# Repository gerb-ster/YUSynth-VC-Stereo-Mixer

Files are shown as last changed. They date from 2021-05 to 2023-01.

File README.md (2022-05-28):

# YUSynth-VC-Stereo-Mixer

This is my eurorack adaptation of the Mixout-VC Panner from YUSynth. I've ommited
the headphone out the VU meters. This is done because to compact the boards a bit
and to save space on the panels.

I've broken it up into 3 boards, one VoiceBoard for every channel, a mainboard 
containing the mixer and the Bass & Trebble and finally small daughter board for the
left/right output jacks.

The breaks up of the boards is done in such a way that you can decide for yourself
how many channels/voice you want to add.

The original design:
http://yusynth.net/Modular/EN/MIXOUT/index.html

## Status: (Almost) Finished

- done: first schematic & board design
- done: breadboard and test
- done: design frontpanel
- done: order PCB and build prototype
- todo: build frontpanel

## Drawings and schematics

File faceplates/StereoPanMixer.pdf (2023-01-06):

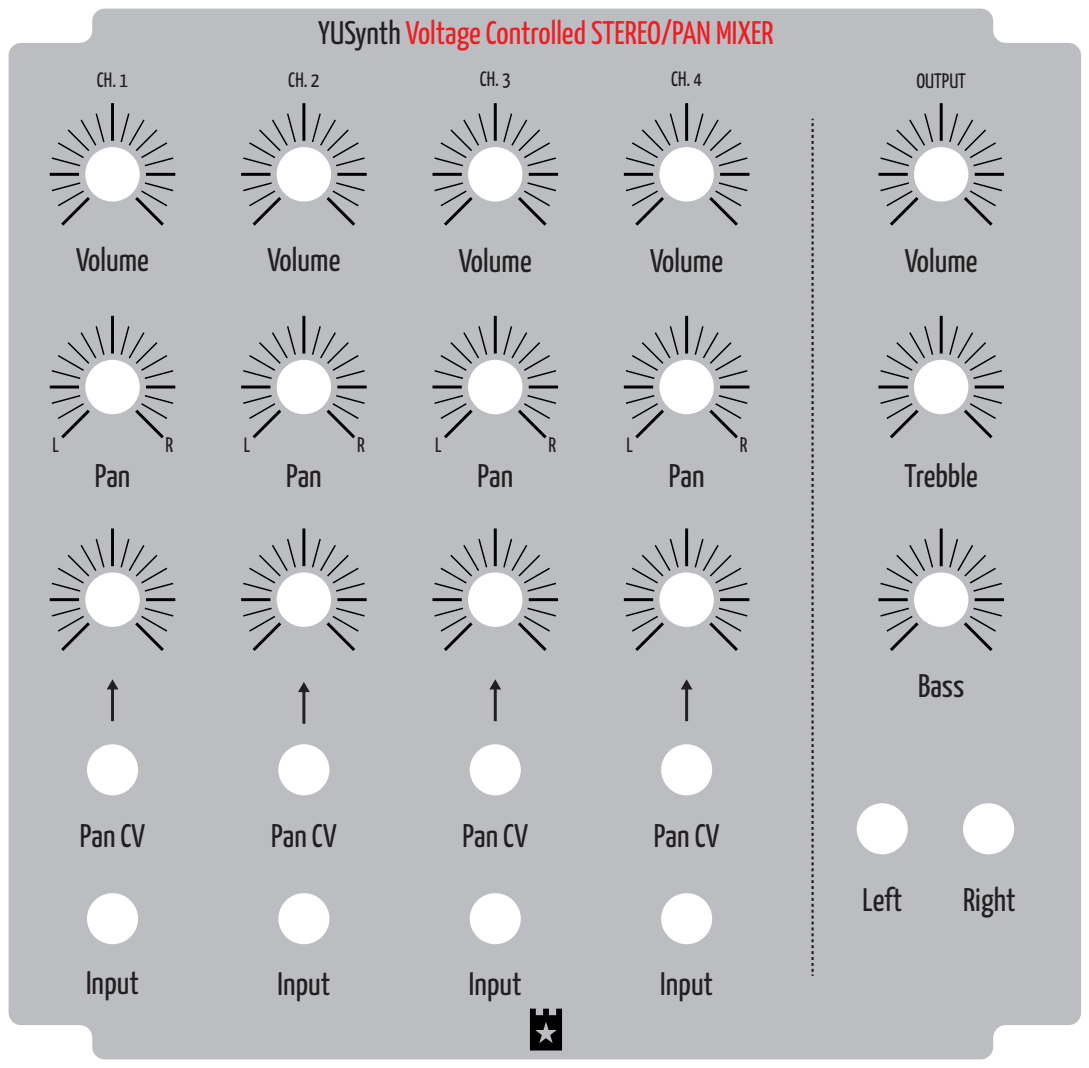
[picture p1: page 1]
Volume; Pan; Trebble; Bass; Pan CV; Input; Left; Right; OUTPUT

YUSynth Voltage Controlled STEREO/PAN MIXER

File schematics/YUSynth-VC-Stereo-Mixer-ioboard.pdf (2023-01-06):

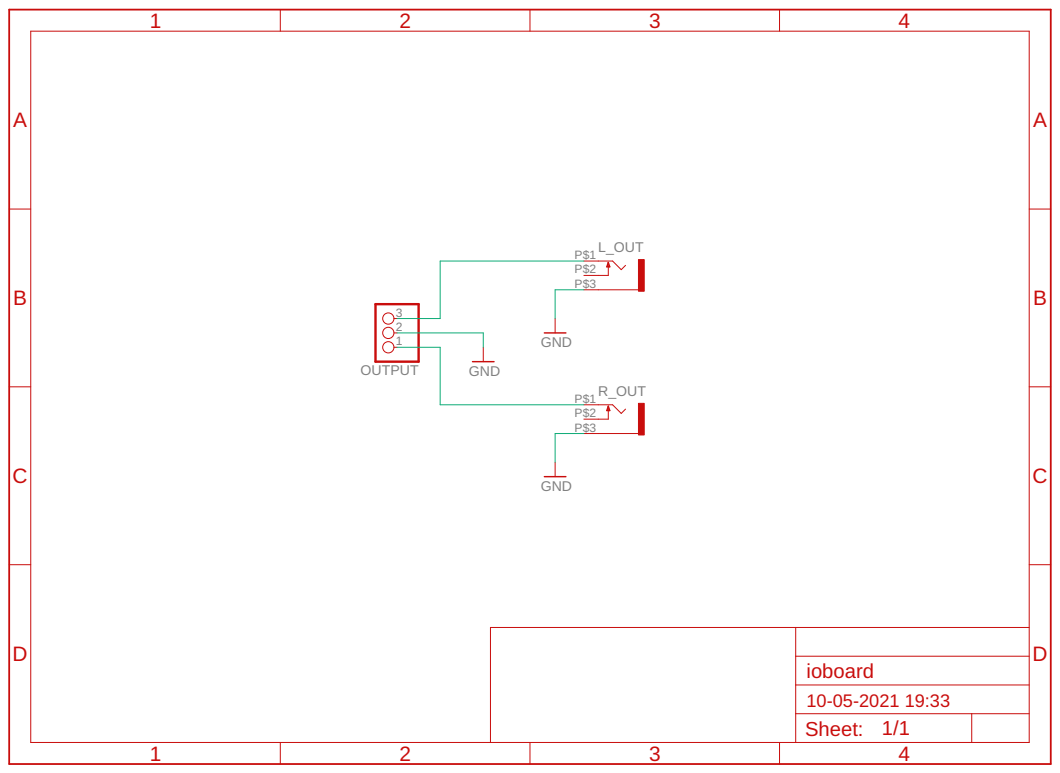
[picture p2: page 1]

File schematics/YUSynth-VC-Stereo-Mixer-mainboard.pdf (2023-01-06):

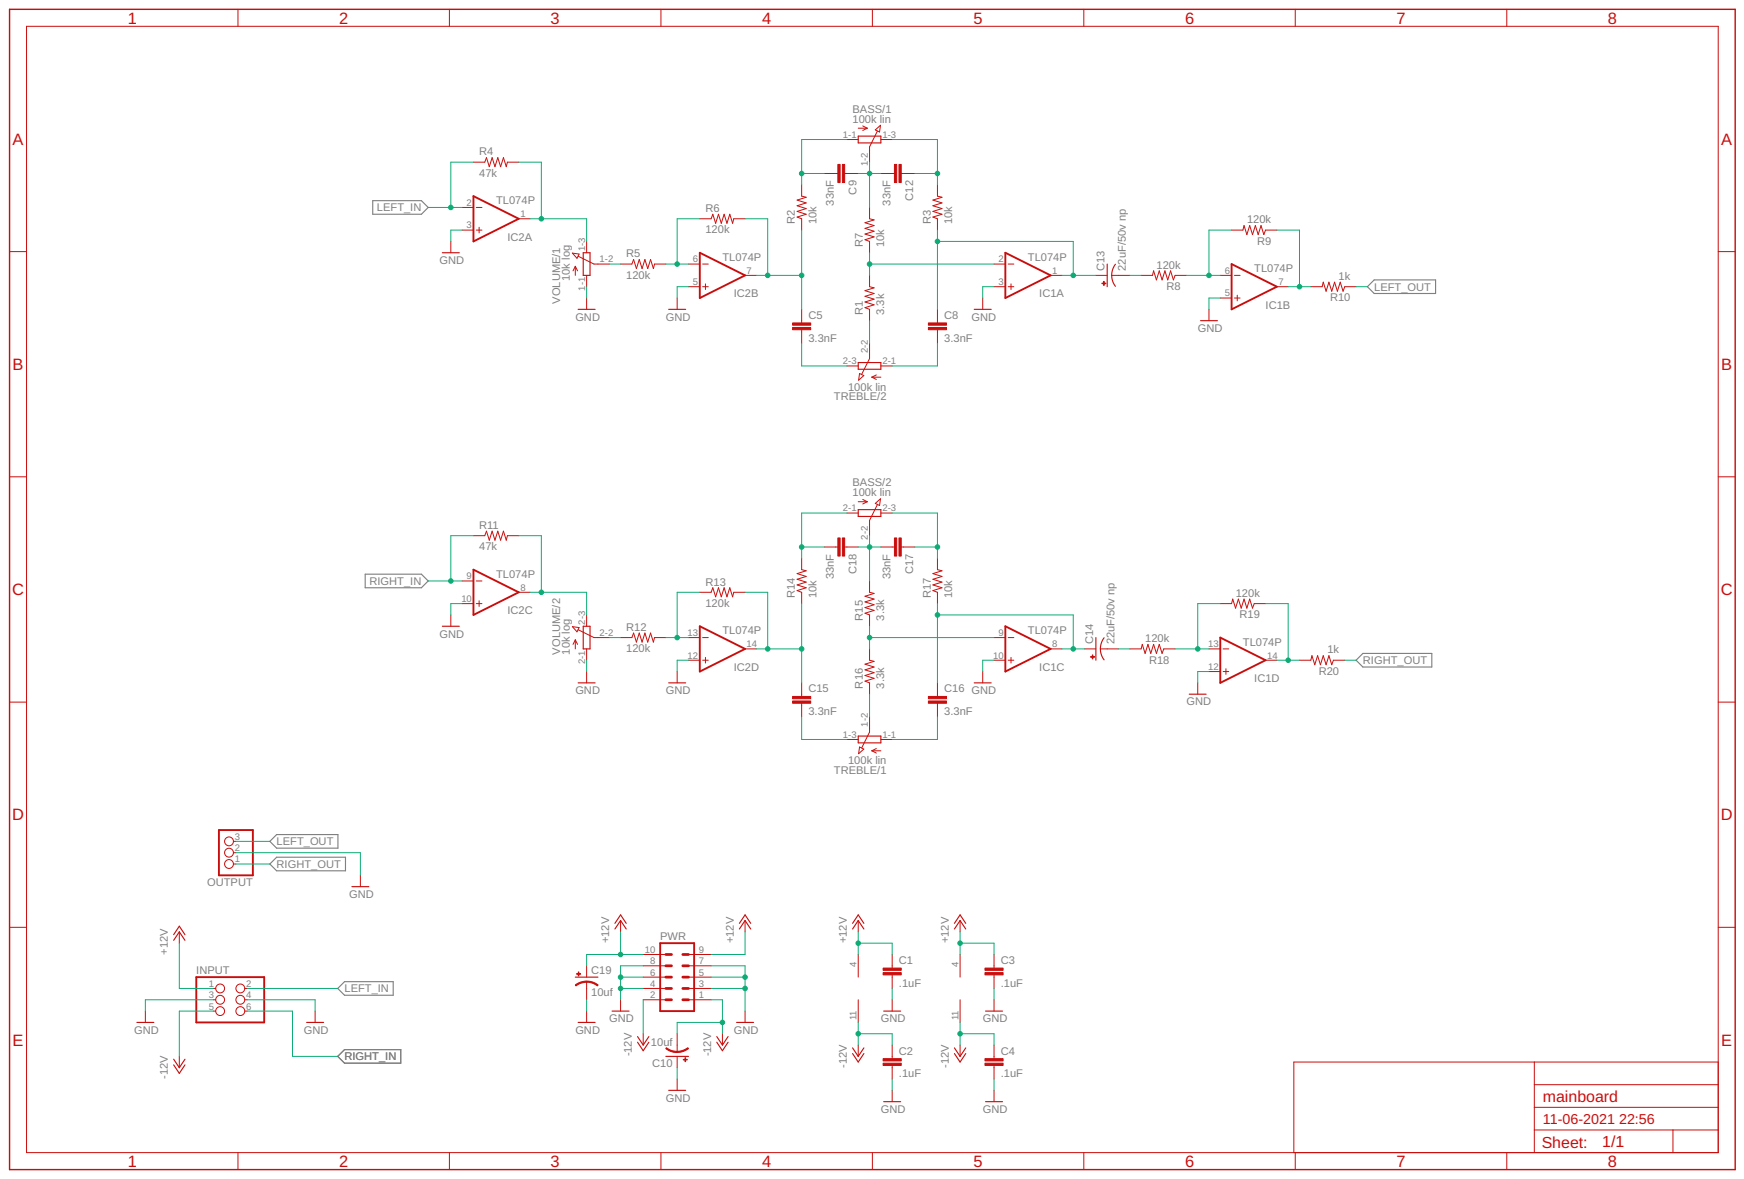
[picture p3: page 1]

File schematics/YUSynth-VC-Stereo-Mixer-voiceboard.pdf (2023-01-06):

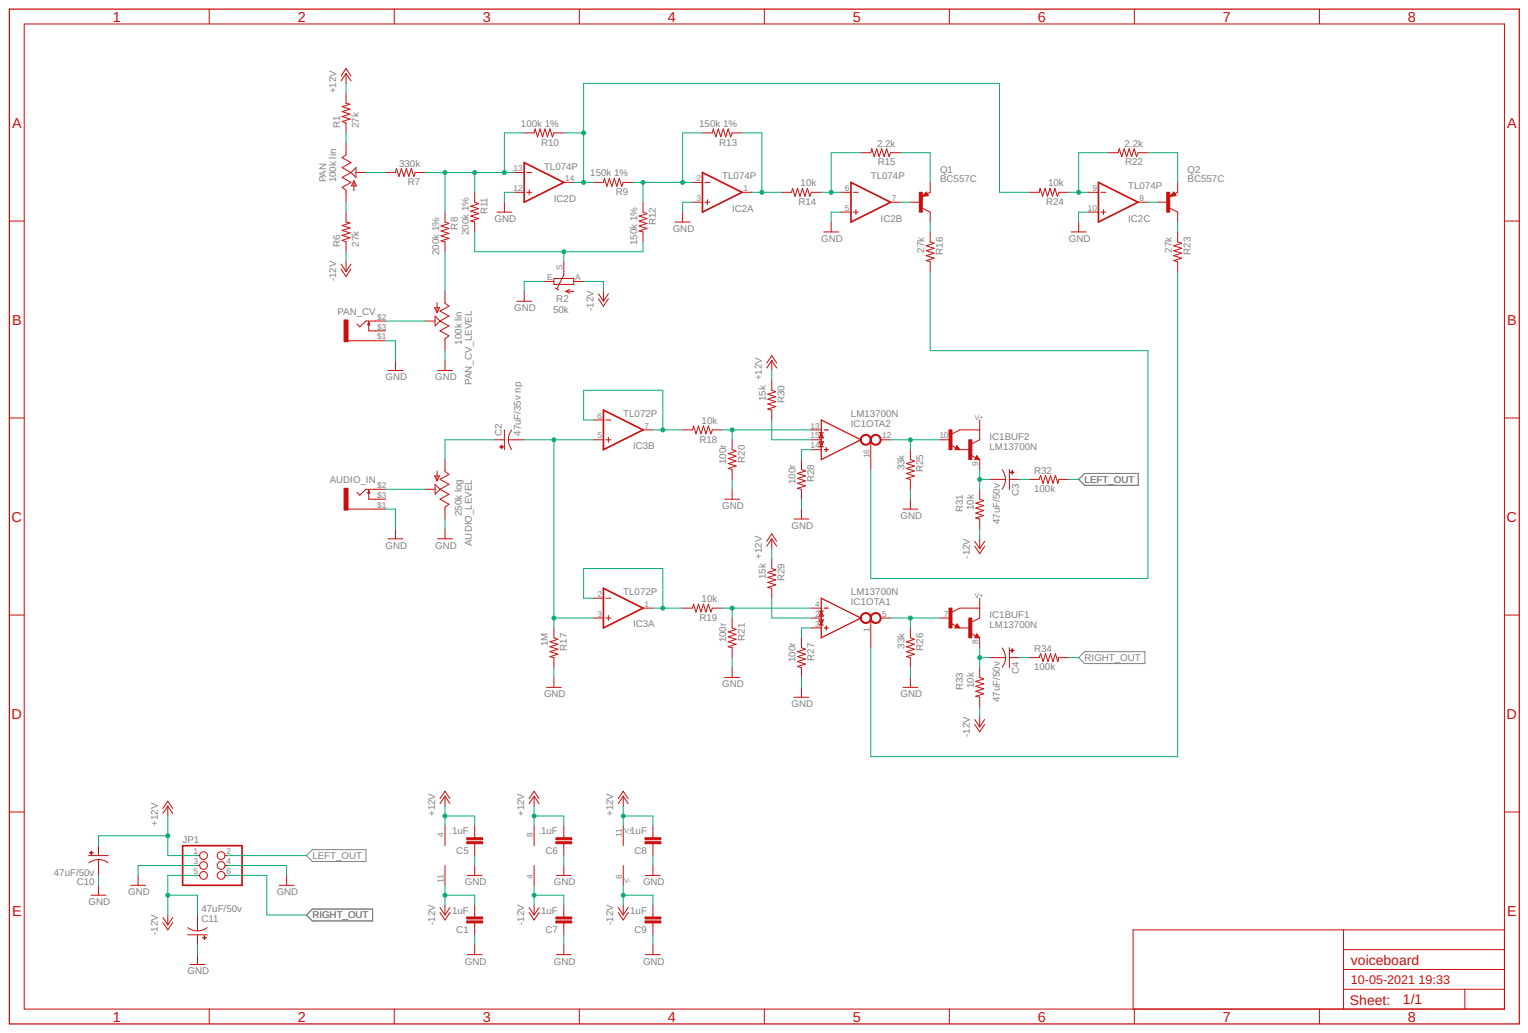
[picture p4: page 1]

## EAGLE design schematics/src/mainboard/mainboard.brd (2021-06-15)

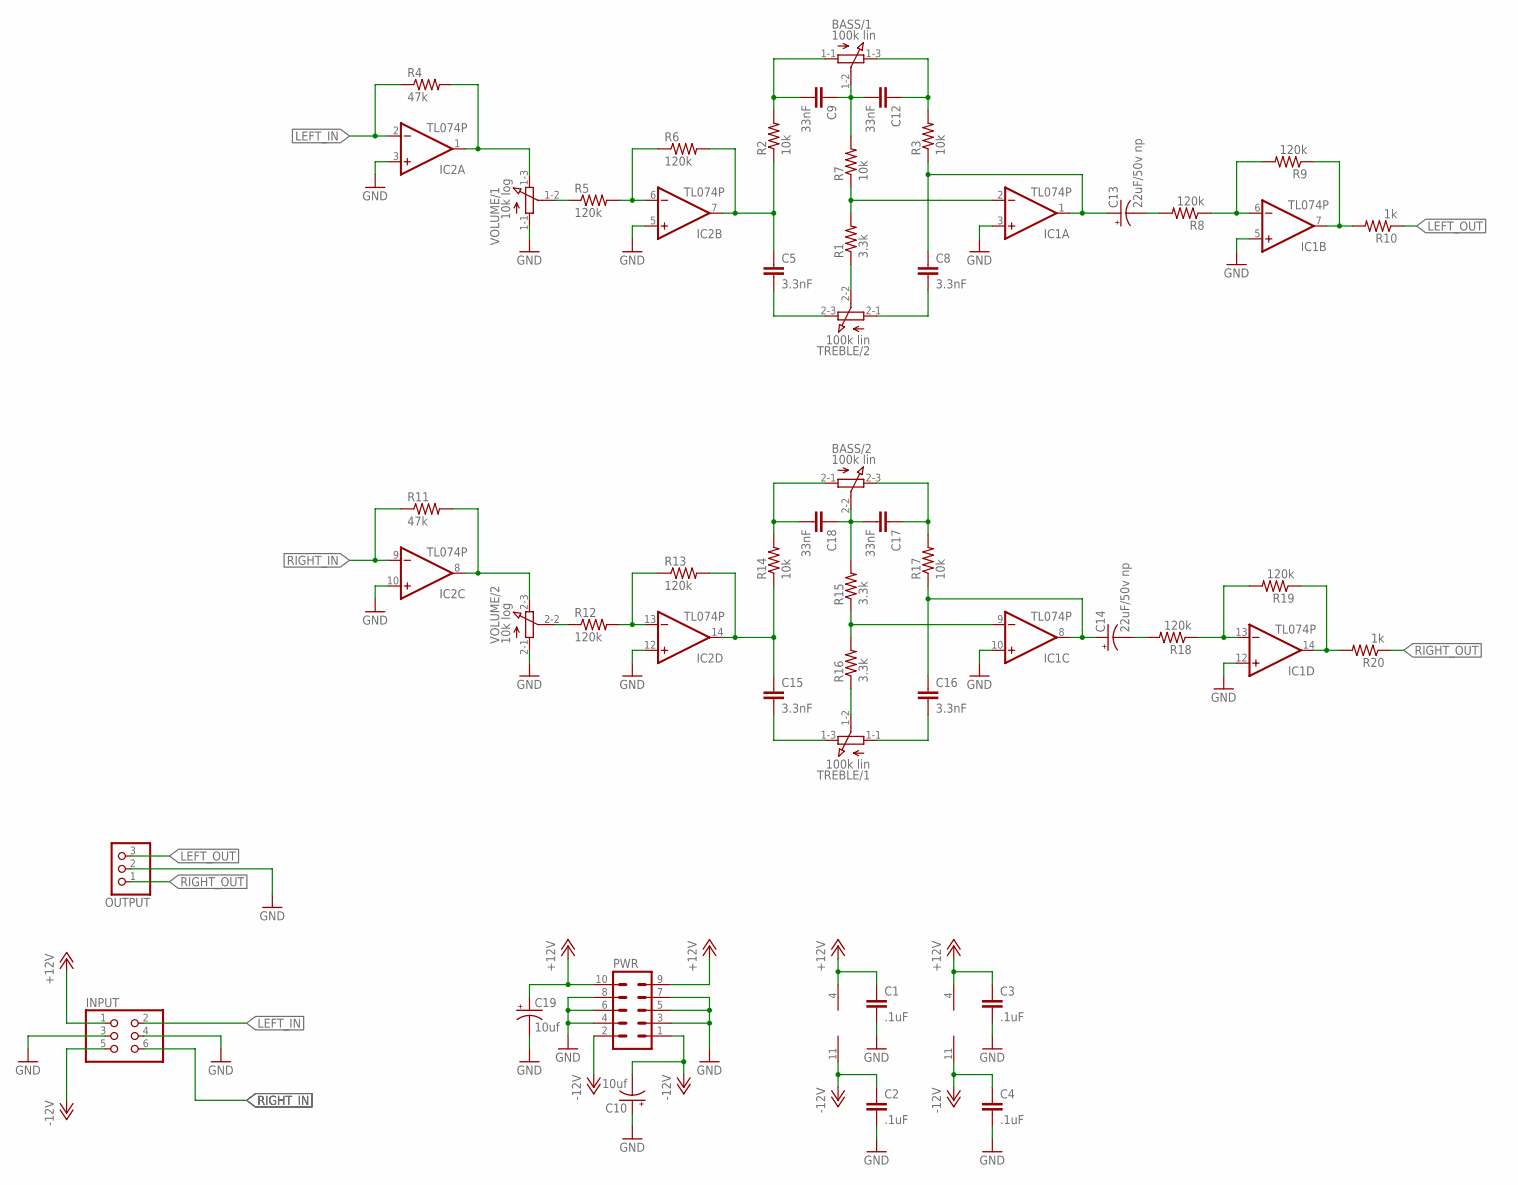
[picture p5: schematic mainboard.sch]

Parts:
BASS: 100k lin; 3RP/1610G
C1, C2, C3, C4: .1uF; C050-024X044
C5, C8, C15, C16: 3.3nF; C050-025X075
C9, C12, C17, C18: 33nF; C050-025X075
C10, C19: 10uf; E2,5-5
C13, C14: 22uF/50v np; E5-10,5
IC1, IC2: TL074P; DIL14
INPUT: PINHD-2X3/90; 2X03/90
OUTPUT: PINHD-1X3; 1X03
PWR: ML10
R1, R15, R16: 3.3k; 0207/7
R2, R3, R7, R14, R17: 10k; 0207/7
R4, R11: 47k; 0207/7
R5, R6, R8, R9, R12, R13, R18, R19: 120k; 0207/7
R10, R20: 1k; 0207/7
TREBLE: 100k lin; 3RP/1610G
VOLUME: 10k log; 3RP/1610G

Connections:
+12V: C1.1, C3.1, C19.+, IC1.4 (V+), IC2.4 (V+), INPUT.1, PWR.9, PWR.10
-12V: C2.1, C4.1, C10.-, IC1.11 (V-), IC2.11 (V-), INPUT.5, PWR.1, PWR.2
GND: C1.2, C2.2, C3.2, C4.2, C10.+, C19.-, IC1.3 (+IN), IC1.5 (+IN), IC1.10 (+IN), IC1.12 (+IN), IC2.3 (+IN), IC2.5 (+IN), IC2.10 (+IN), IC2.12 (+IN), INPUT.3, INPUT.4, OUTPUT.2, PWR.3, PWR.4, PWR.5, PWR.6, PWR.7, PWR.8, VOLUME.1-1 (A), VOLUME.2-1 (A)
LEFT_IN: IC2.2 (-IN), INPUT.2, R4.1
LEFT_OUT: OUTPUT.3, R10.1
unnamed: R5.1, VOLUME.1-2 (S)
unnamed: IC2.1 (OUT), R4.2, VOLUME.1-3 (E)
unnamed: IC2.6 (-IN), R5.2, R6.1
unnamed: C5.1, IC2.7 (OUT), R2.1, R6.2
unnamed: R1.1, TREBLE.2-2 (S)
unnamed: C5.2, TREBLE.2-3 (E)
unnamed: C8.2, TREBLE.2-1 (A)
unnamed: BASS.1-1 (A), C9.2, R2.2
unnamed: BASS.1-3 (E), C12.1, R3.2
unnamed: BASS.1-2 (S), C9.1, C12.2, R7.2
unnamed: IC1.2 (-IN), R1.2, R7.1
unnamed: C8.1, C13.+, IC1.1 (OUT), R3.1
unnamed: IC1.6 (-IN), R8.1, R9.2
unnamed: IC1.7 (OUT), R9.1, R10.2
unnamed: C13.-, R8.2
unnamed: C15.2, TREBLE.1-3 (E)
unnamed: IC2.8 (OUT), R11.2, VOLUME.2-3 (E)
unnamed: R12.1, VOLUME.2-2 (S)
unnamed: IC2.13 (-IN), R12.2, R13.1
unnamed: C16.2, TREBLE.1-1 (A)
unnamed: R16.1, TREBLE.1-2 (S)
unnamed: C15.1, IC2.14 (OUT), R13.2, R14.1
unnamed: IC1.9 (-IN), R15.1, R16.2
unnamed: BASS.2-2 (S), C17.2, C18.1, R15.2
unnamed: BASS.2-1 (A), C18.2, R14.2
unnamed: BASS.2-3 (E), C17.1, R17.2
unnamed: C14.-, R18.2
unnamed: C14.+, C16.1, IC1.8 (OUT), R17.1
unnamed: IC1.13 (-IN), R18.1, R19.2
unnamed: IC1.14 (OUT), R19.1, R20.2
RIGHT_IN: IC2.9 (-IN), INPUT.6, R11.1
RIGHT_OUT: OUTPUT.1, R20.1

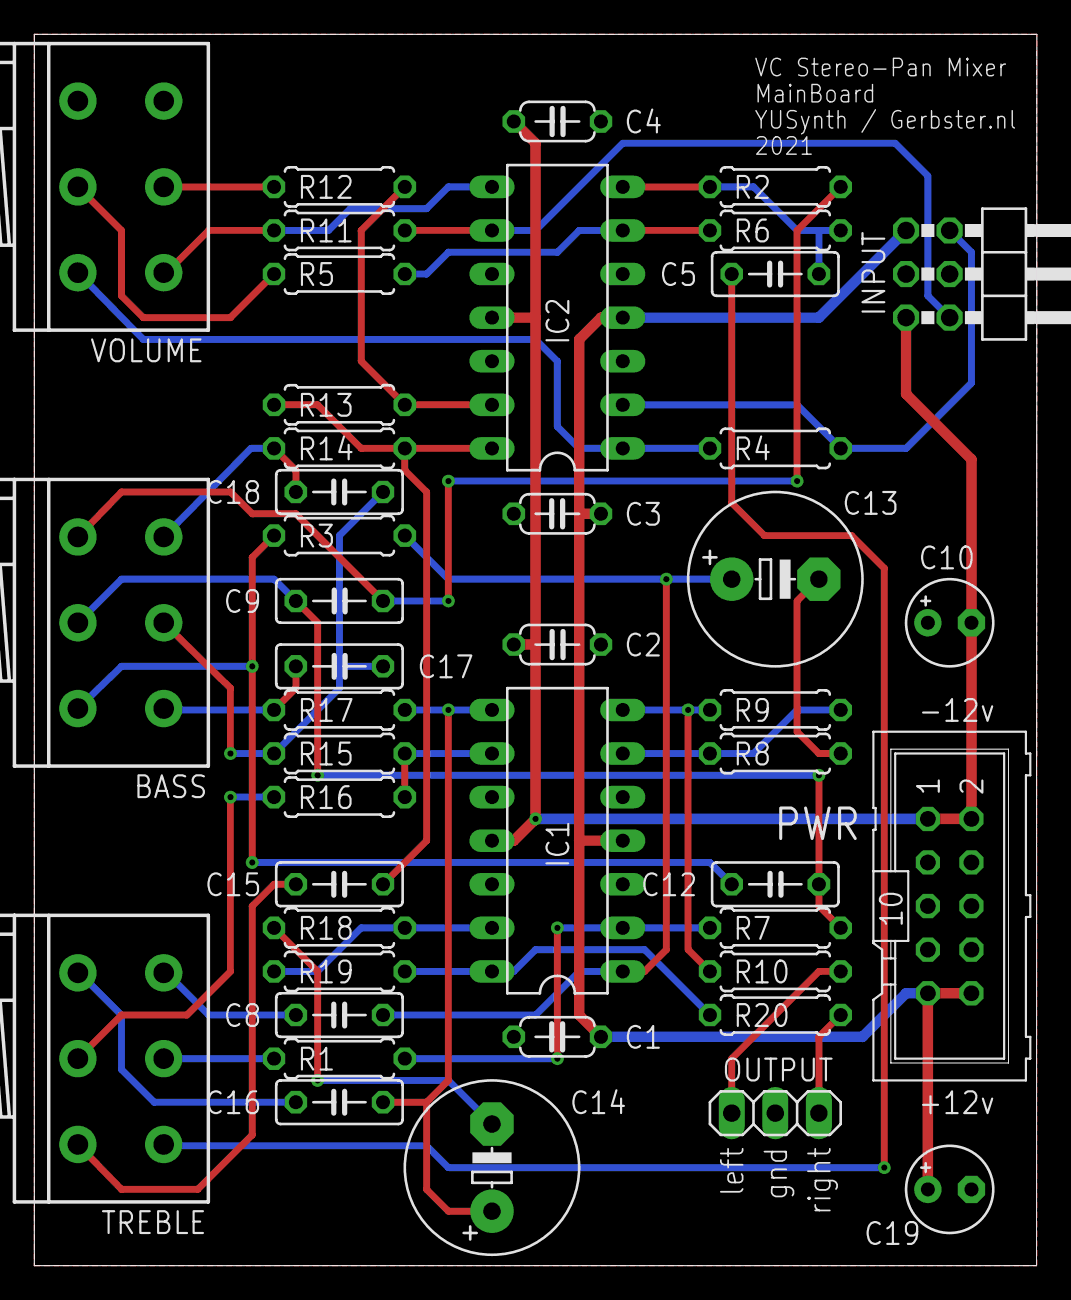
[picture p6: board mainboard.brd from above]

Board: 2 copper layers, 58.4 x 71.8 mm, 44 parts (0 on the bottom side), 37 nets.

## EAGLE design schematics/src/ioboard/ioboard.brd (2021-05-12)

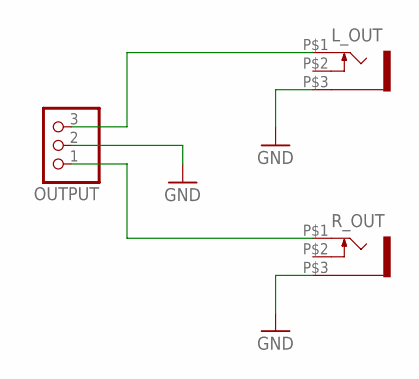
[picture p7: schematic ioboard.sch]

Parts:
L_OUT: WQP-PJ301M-12_JACK
OUTPUT: PINHD-1X3; 1X03
R_OUT: WQP-PJ301M-12_JACK

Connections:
GND: L_OUT.P$3 (1), OUTPUT.2, R_OUT.P$3 (1)
LEFT_OUT: L_OUT.P$1 (2), OUTPUT.3
RIGHT_OUT: OUTPUT.1, R_OUT.P$1 (2)

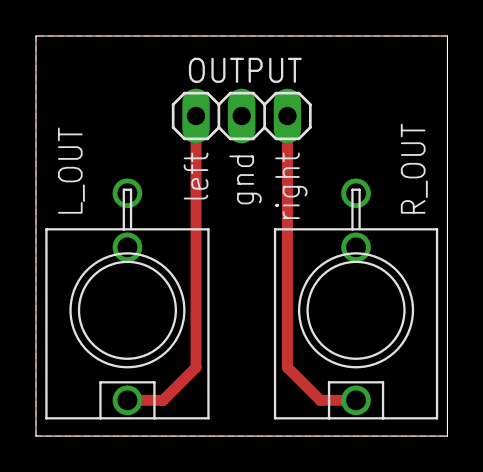
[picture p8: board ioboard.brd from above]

Board: 2 copper layers, 22.9 x 22.2 mm, 3 parts (0 on the bottom side), 3 nets.

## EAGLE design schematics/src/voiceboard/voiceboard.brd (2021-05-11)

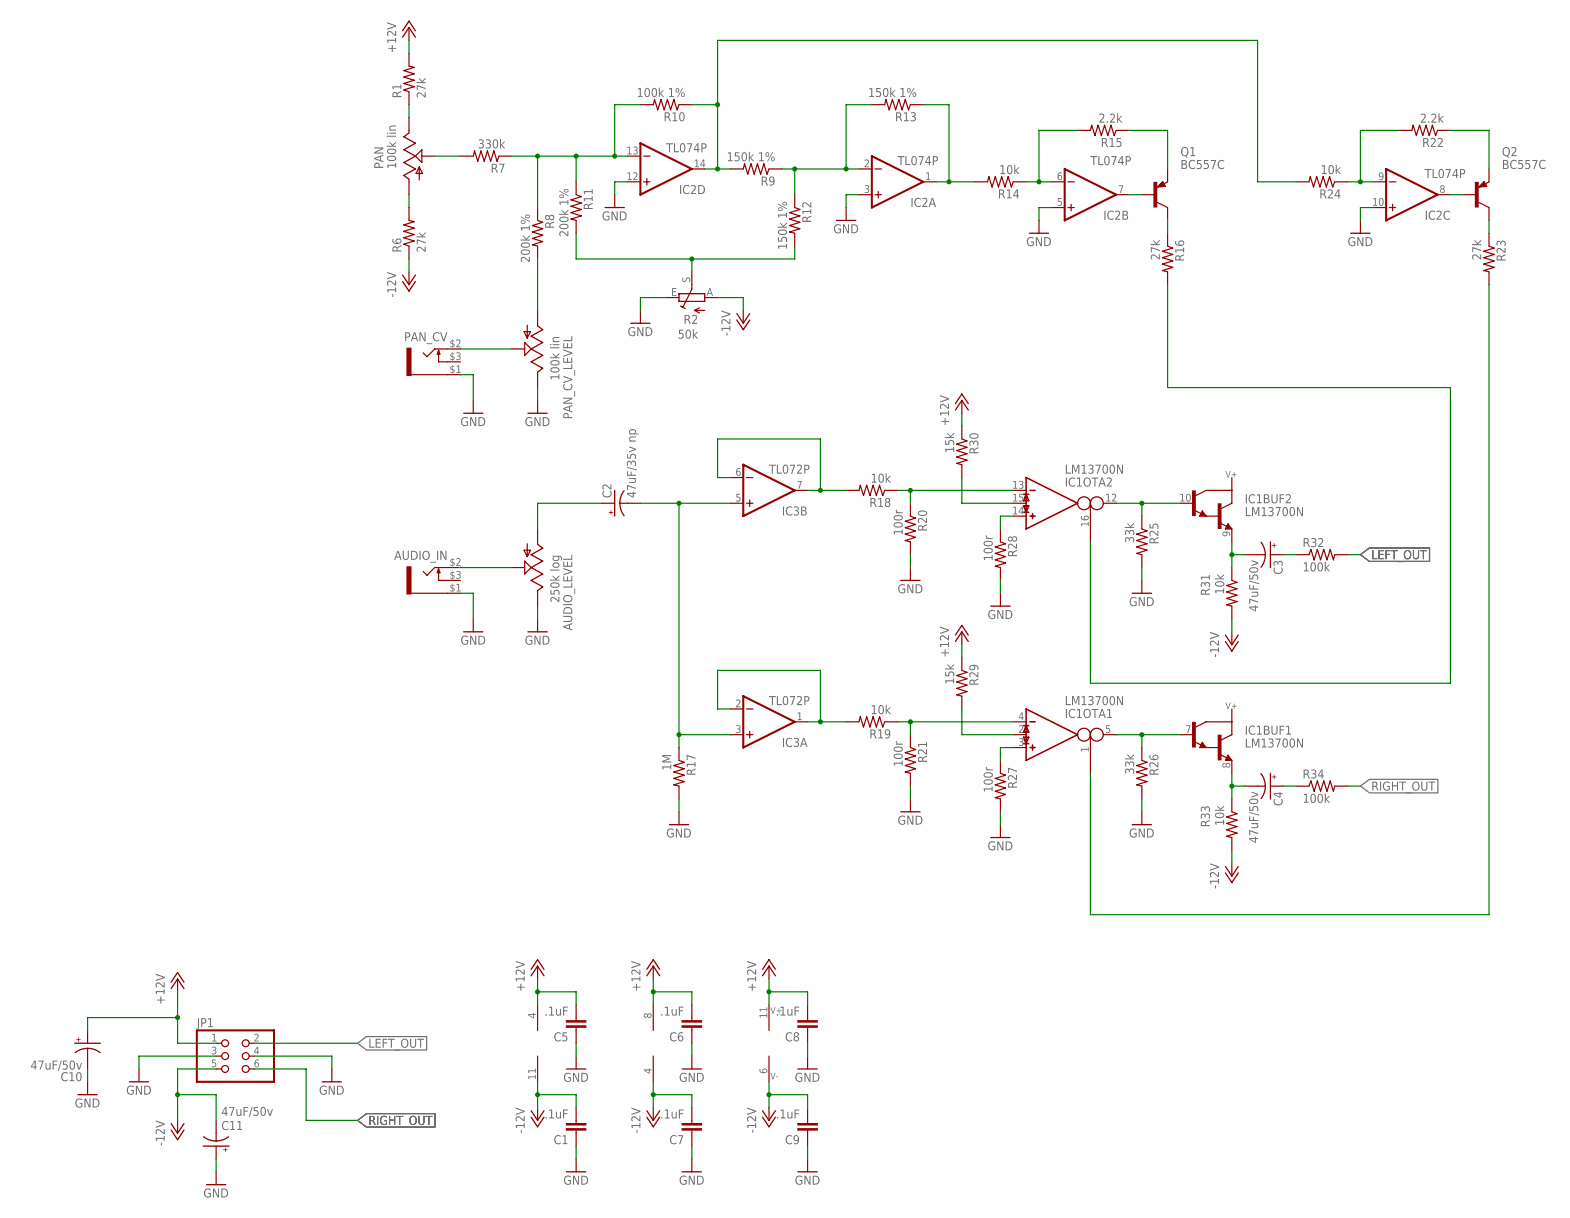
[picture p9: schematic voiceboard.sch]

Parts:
AUDIO_IN: PJ-323PJ-323; PJ-323
AUDIO_LEVEL: 250k log; EVUF
C1, C5, C6, C7, C8, C9: .1uF; C050-024X044
C2: 47uF/35v np; E5-10,5
C3, C4, C10, C11: 47uF/50v; E2,5-6
IC1: LM13700N; DIL16
IC2: TL074P; DIL14
IC3: TL072P; DIL08
JP1: PINHD-2X3/90; 2X03/90
PAN: 100k lin; EVUF
PAN_CV: PJ-323PJ-323; PJ-323
PAN_CV_LEVEL: 100k lin; EVUF
Q1, Q2: BC557C; TO92-EBC
R1, R6, R16, R23: 27k; 0207/7
R2: 50k; S64YW
R7: 330k; 0207/7
R8, R11: 200k 1%; 0207/7
R9, R12, R13: 150k 1%; 0207/7
R10: 100k 1%; 0207/7
R14, R18, R19, R24, R31, R33: 10k; 0207/7
R15, R22: 2.2k; 0207/7
R17: 1M; 0207/7
R20, R21, R27, R28: 100r; 0207/7
R25, R26: 33k; 0207/7
R29, R30: 15k; 0207/7
R32, R34: 100k; 0207/7

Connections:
+12V: C5.2, C6.2, C8.2, C10.+, IC1.11 (V+), IC2.4 (V+), IC3.8 (V+), JP1.1, R1.2, R29.1, R30.1
-12V: C1.2, C7.2, C9.2, C11.-, IC1.6 (V-), IC2.11 (V-), IC3.4 (V-), JP1.5, R2.A, R6.1, R31.2, R33.2
GND: AUDIO_IN.$1 (3), AUDIO_LEVEL.3 (E), C1.1, C5.1, C6.1, C7.1, C8.1, C9.1, C10.-, C11.+, IC2.3 (+IN), IC2.5 (+IN), IC2.10 (+IN), IC2.12 (+IN), JP1.3, JP1.4, PAN_CV.$1 (3), PAN_CV_LEVEL.3 (E), R2.E, R17.2, R20.2, R21.2, R25.2, R26.2, R27.2, R28.2
LEFT_OUT: JP1.2, R32.2
unnamed: PAN.3 (E), R1.1
unnamed: PAN.1 (A), R6.2
unnamed: PAN.2 (S), R7.2
unnamed: PAN_CV.$2 (1), PAN_CV_LEVEL.2 (S)
unnamed: IC2.13 (-IN), R7.1, R8.1, R10.2, R11.1
unnamed: IC2.14 (OUT), R9.2, R10.1, R24.2
unnamed: PAN_CV_LEVEL.1 (A), R8.2
unnamed: IC2.1 (OUT), R13.1, R14.2
unnamed: R2.S, R11.2, R12.2
unnamed: IC2.2 (-IN), R9.1, R12.1, R13.2
unnamed: IC2.6 (-IN), R14.1, R15.2
unnamed: IC2.7 (OUT), Q1.B
unnamed: Q1.C, R16.1
unnamed: Q1.E, R15.1
unnamed: AUDIO_IN.$2 (1), AUDIO_LEVEL.2 (S)
unnamed: AUDIO_LEVEL.1 (A), C2.+
unnamed: C2.-, IC3.3 (+IN), IC3.5 (+IN), R17.1
unnamed: IC3.1 (OUT), IC3.2 (-IN), R19.2
unnamed: IC3.6 (-IN), IC3.7 (OUT), R18.2
unnamed: IC1.4 (IN_N), R19.1, R21.1
unnamed: IC1.13 (IN_N), R18.1, R20.1
unnamed: IC2.8 (OUT), Q2.B
unnamed: IC2.9 (-IN), R22.2, R24.1
unnamed: Q2.E, R22.1
unnamed: Q2.C, R23.1
unnamed: IC1.10 (B), IC1.12 (OUT), R25.1
unnamed: IC1.5 (OUT), IC1.7 (B), R26.1
unnamed: IC1.14 (IN_P), R28.1
unnamed: IC1.3 (IN_P), R27.1
unnamed: IC1.15 (I_DIODE), R30.2
unnamed: IC1.2 (I_DIODE), R29.2
unnamed: C3.-, IC1.9 (E), R31.1
unnamed: C3.+, R32.1
unnamed: C4.-, IC1.8 (E), R33.1
unnamed: C4.+, R34.1
unnamed: IC1.16 (I_BIAS), R16.2
unnamed: IC1.1 (I_BIAS), R23.2
RIGHT_OUT: JP1.6, R34.2

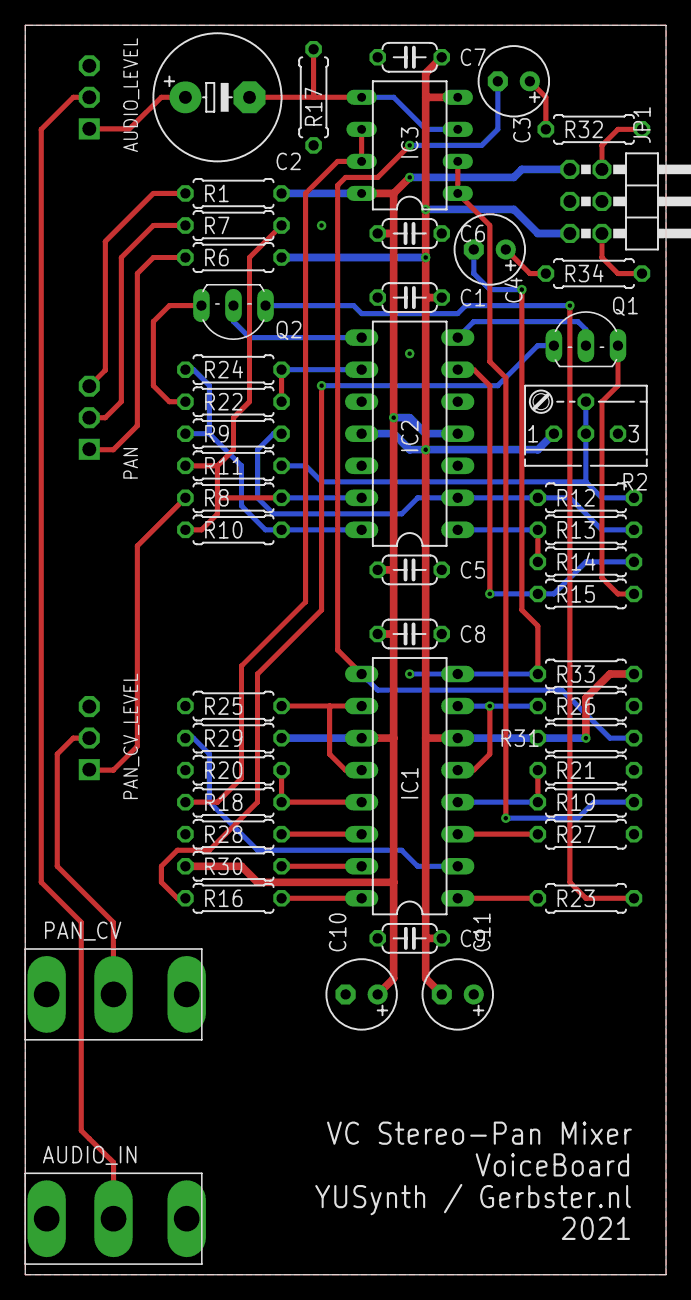
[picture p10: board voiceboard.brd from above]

Board: 2 copper layers, 50.8 x 99.1 mm, 53 parts (0 on the bottom side), 42 nets.

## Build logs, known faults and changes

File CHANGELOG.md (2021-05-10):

# Changelog

All notable changes to this project will be documented in this file.

The format is based on [Keep a Changelog](https://keepachangelog.com/en/1.0.0/),
and this project adheres to [Semantic Versioning](https://semver.org/spec/v2.0.0.html).

## [1.0.0] - 2021-10-05

### Added

- Inintial repo setup
- Added schematics & board designs

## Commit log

2021-05-10 Added Status
    [YUSynth-VC-Stereo-Mixer-ioboard.GBL, YUSynth-VC-Stereo-Mixer-ioboard.GBO, YUSynth-VC-Stereo-Mixer-ioboard.GBP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]
2021-05-11 Added Status & Images
    [voiceboard.brd]
2021-05-12 Added Faceplates
    [YUSynth-VC-Stereo-Mixer-ioboard.GBL, YUSynth-VC-Stereo-Mixer-ioboard.GBS, YUSynth-VC-Stereo-Mixer-ioboard.GKO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]
2021-06-15 Updated Schematics, Fixed Power Socket orientation
    [YUSynth-VC-Stereo-Mixer-ioboard.XLN, YUSynth-VC-Stereo-Mixer-mainboard.GBL, YUSynth-VC-Stereo-Mixer-mainboard.GBS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]
2021-08-06 Updated some schematics and docs
    [YUSynth-VC-Stereo-Mixer-ioboard.GBL, YUSynth-VC-Stereo-Mixer-ioboard.GBO, YUSynth-VC-Stereo-Mixer-ioboard.GBP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]
2021-08-10 Fixed some bugs and updated documentation
    [YUSynth-VC-Stereo-Mixer-ioboard.XLN, YUSynth-VC-Stereo-Mixer-mainboard.XLN, YUSynth-VC-Stereo-Mixer-voiceboard.XLN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]
2022-04-20 Some updates & bugfixes
    [YUSynth-VC-Stereo-Mixer-ioboard.XLN, YUSynth-VC-Stereo-Mixer-mainboard.XLN, YUSynth-VC-Stereo-Mixer-voiceboard.XLN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]
2022-04-22 Fixed schematics & descriptions
    [YUSynth-VC-Stereo-Mixer-ioboard.XLN, YUSynth-VC-Stereo-Mixer-mainboard.XLN, YUSynth-VC-Stereo-Mixer-voiceboard.XLN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]
2022-05-17 Updated Firmware
    [YUSynth-VC-Stereo-Mixer-ioboard.XLN, YUSynth-VC-Stereo-Mixer-mainboard.XLN, YUSynth-VC-Stereo-Mixer-voiceboard.XLN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]
2022-05-18 Updated Faceplates
    [YUSynth-VC-Stereo-Mixer-ioboard.XLN, YUSynth-VC-Stereo-Mixer-mainboard.XLN, YUSynth-VC-Stereo-Mixer-voiceboard.XLN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]
2022-05-18 Fixed issues
    [YUSynth-VC-Stereo-Mixer-ioboard.XLN, YUSynth-VC-Stereo-Mixer-mainboard.XLN, YUSynth-VC-Stereo-Mixer-voiceboard.XLN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]
2022-05-21 Fixed schematics
    [YUSynth-VC-Stereo-Mixer-ioboard.XLN, YUSynth-VC-Stereo-Mixer-mainboard.XLN, YUSynth-VC-Stereo-Mixer-voiceboard.XLN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]
2022-05-28 General updates
    [copper_bottom.gbr, copper_top.gbr, drills.xln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]
2022-06-13 Faceplates & Bugfixes
    [drills.xln, gerber_job.gbrjob]
